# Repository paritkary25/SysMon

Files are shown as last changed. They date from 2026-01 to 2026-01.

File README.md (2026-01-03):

# SysMon
SysMon is a system monitor hardware. It has three parts
- USB hub
- macro keys and a volume knob as an input (knobs are cool)
- three strips of multiple colours showing CPU/GPU/RAM usage
The project is ongoing.

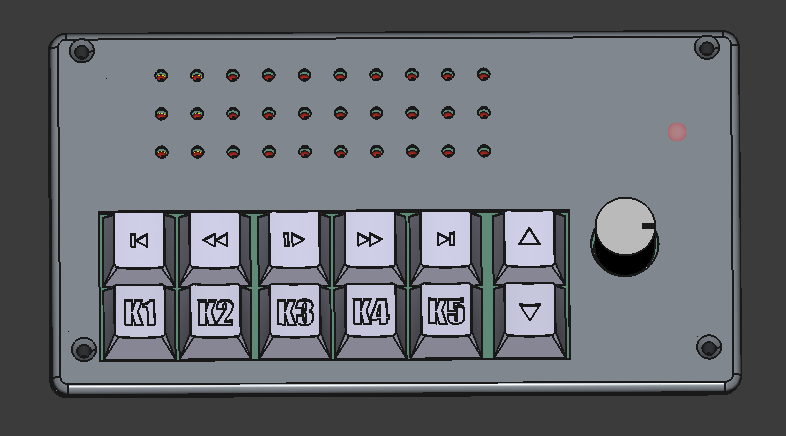
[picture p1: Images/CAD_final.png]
CAD Image


.
├── CAD: Contains all the CADs related to the project
├── PCB: Contains the PCB files
├── Software: Software used in this project
└── USB-C_dim_xtracn: An overkill exercise to obtain the correct placement of the holes of the USB-C module

## Progress
- CAD: Complete and printed
- PCB: Complete and printed
    - The USB hub is working
    - STM32 is yet to be tested
- Software: In progress

## Mechanical CAD

The CAD is 3D printed. The enclosure is made slanted to appear like a table clock. The angle is chosen such that it will look good just below the main monitor. The SysMon uses standard Cherry MX keys. Custom keys can be used.

Some of the STEPs are taken from other open-source projects; a sincere thank you to them.

### Log
The CAD has a minor mistake that I noticed after the printing. The inner side of the back body has the wrong angle. Please correct it before printing for yourself. 

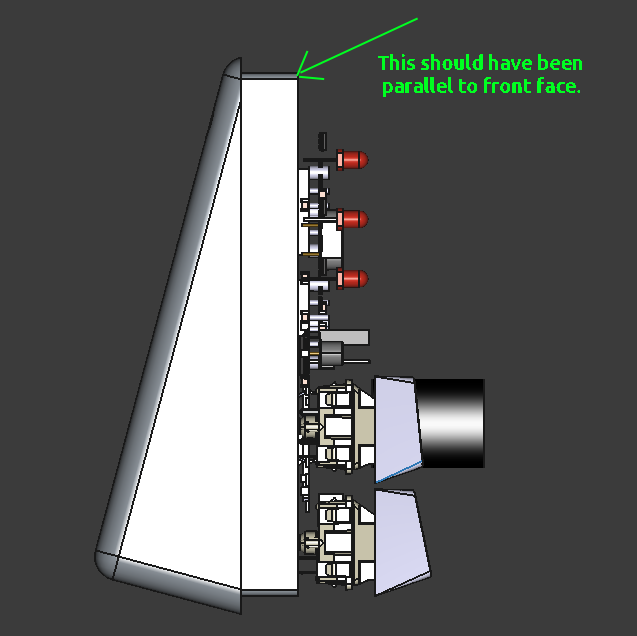
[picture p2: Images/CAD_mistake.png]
CAD Image


## Electronics 
The electronics consist of

- switch matrix
- LED matrix
- volume knob
- Two USB-A upstream ports
- USB-C downstream port for connection to PC
- Adjustable step-down converter module to power the hub
- TI TUSB2036 ASIC-based USB hub 
- STM32L412, very low-powered microcontroller

The PCB is designed on KiCad. For this design, two layers are sufficient. Mixed routing is used with ground planes on both sides. Small series resistors are added in series to the USB-A upstream data bus to prevent ESD issues. Array scanning is used for switches, and row scanning is used for LED lighting.

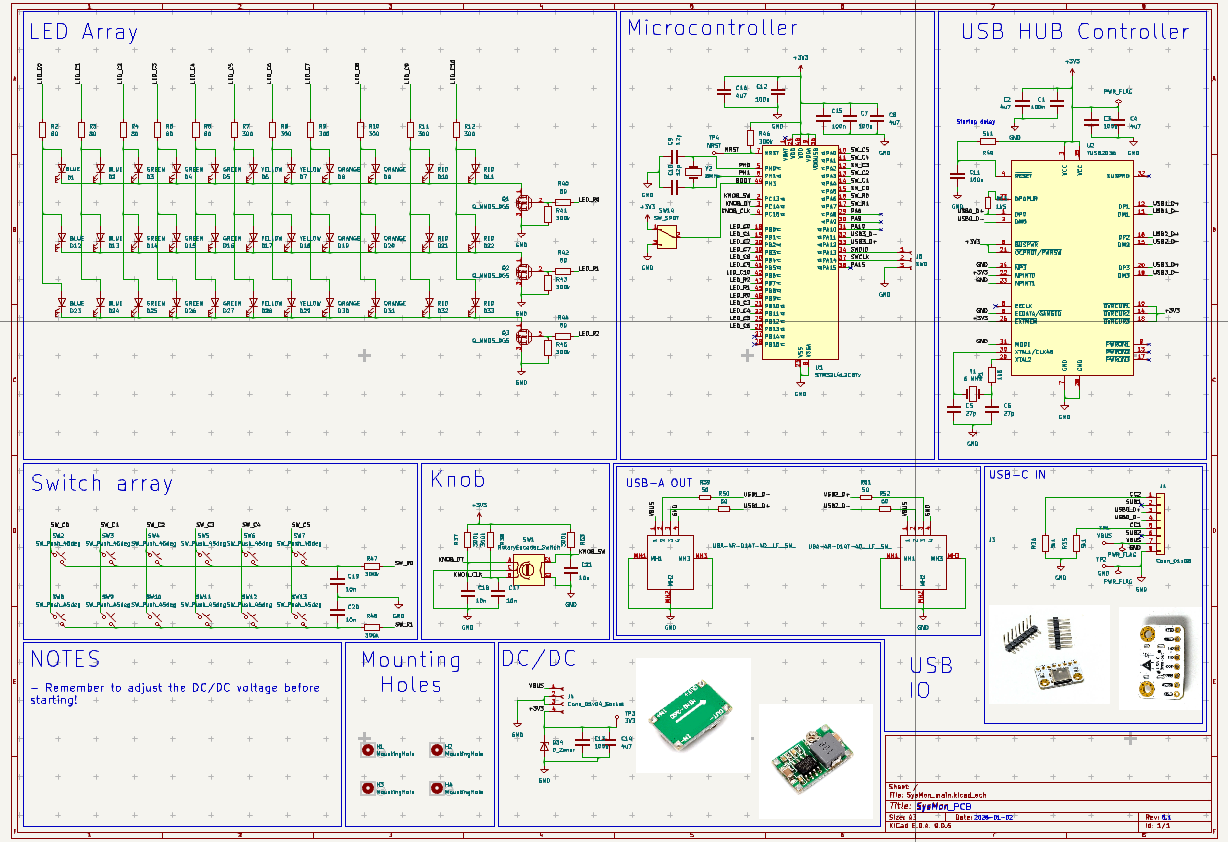
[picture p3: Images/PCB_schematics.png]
Schematics

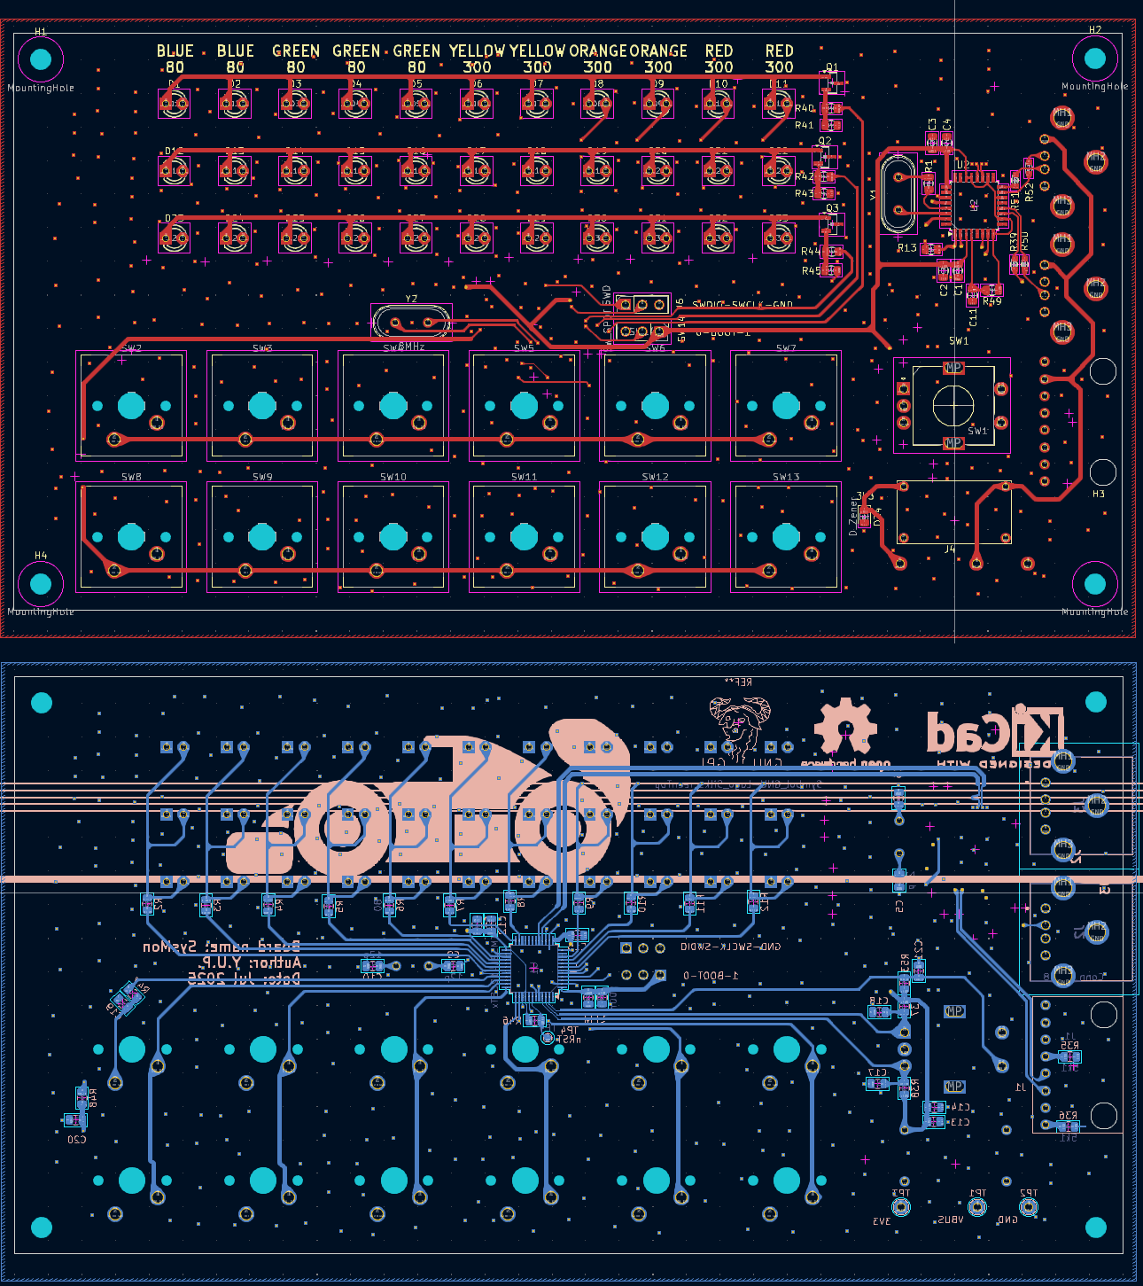
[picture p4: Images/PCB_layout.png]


This hub is not externally powered; take care of what you are plugging in.  The USB-C bus power is set to maximum by pulling CC pins down by 5.1 kOhm (refer to USB-C specifications [USB-C specification](https://www.usb.org/sites/default/files/USB%20Type-C%20Spec%20R2.0%20-%20August%202019_0.pdf) [USB-C PD specifications](https://www.usb.org/sites/default/files/USB-C%20Source%20Power%20Test%20Specification%202021%2005%2024.pdf)))

### Log
- The footprint of the power module is not correct. A workaround involving jumpers and cutting traces is performed.
- The NRST pin of the STM32 is given a test-point only. It is causing discomfort while programming and testing. Please combine it with the SWD programmer pins.

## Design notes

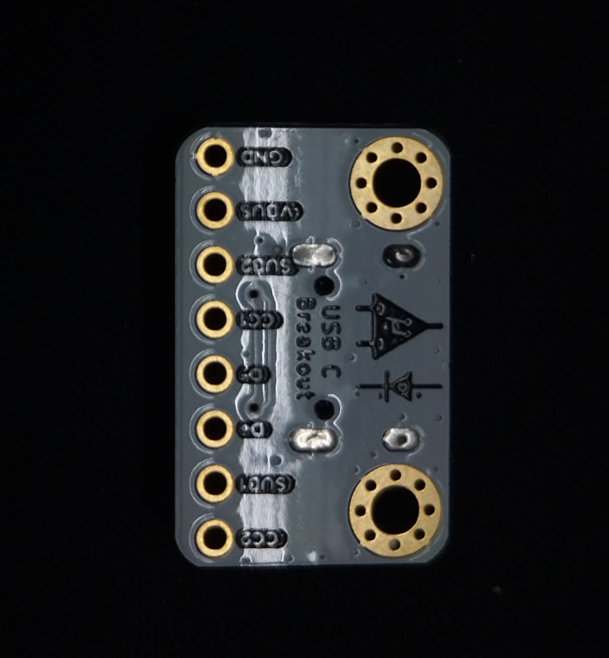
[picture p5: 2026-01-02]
USB-C_dim_xtracn/back.jpg

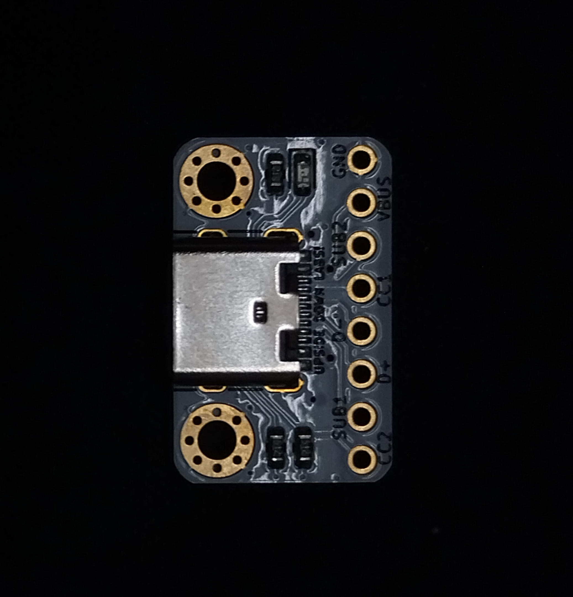
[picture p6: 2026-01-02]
USB-C_dim_xtracn/front.jpg

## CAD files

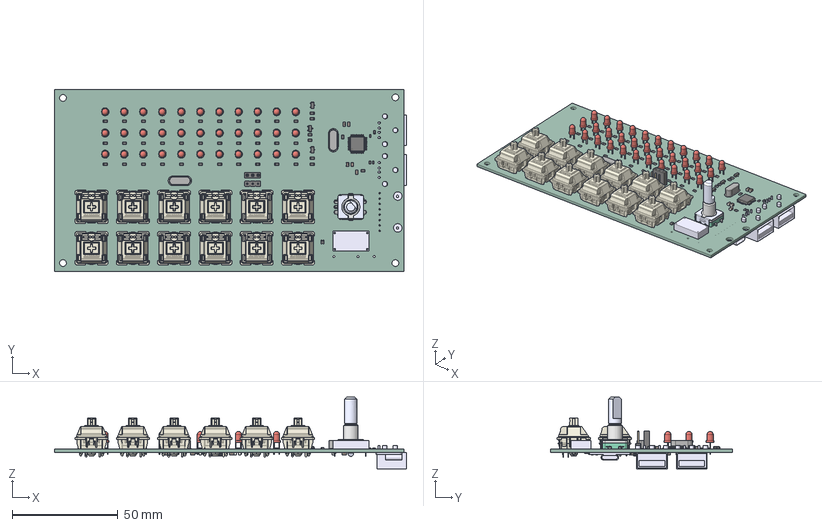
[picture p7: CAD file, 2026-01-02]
PCB/SysMon_main.step
166.2 x 86.0 x 33.9 mm
LED_D3.0mm x 33
R_0805_2012Metric x 48
RD-05C786B9Fyifh x 12
D_0805
PinSocket_1x03_P2.54mm_Vertical
SOT_23 x 3
EC11
Crystal_HC49-4H_Vertical x 2
C_0805_2012Metric x 16
R_0603_1608Metric x 4
PinHeader_1x03_P254mm_Vertical
LQFP_32_7x7mm_P08mm
LQFP_48_7x7mm_P05mm
SysMon_main_PCB

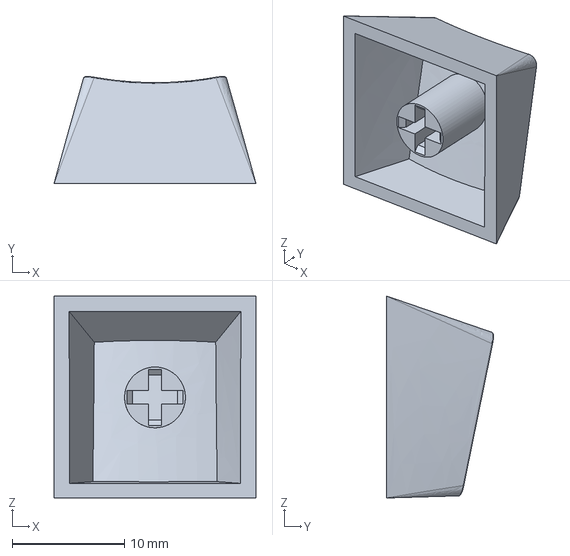
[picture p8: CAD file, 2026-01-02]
CAD/Keys/r2_k4.FCStd
18.0 x 9.53 x 18.0 mm

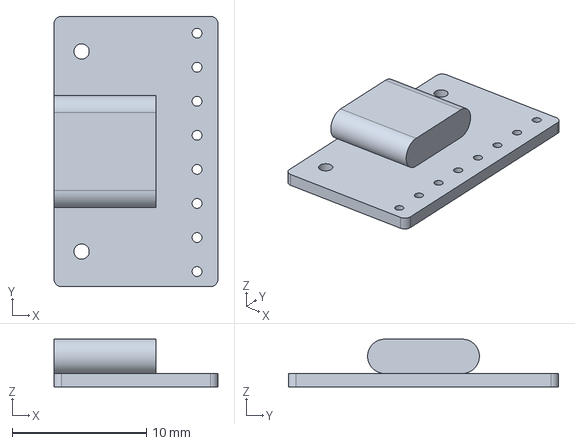
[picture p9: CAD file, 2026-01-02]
USB-C_dim_xtracn/USBC_bo.FCStd
12.2 x 20.2 x 3.56 mm

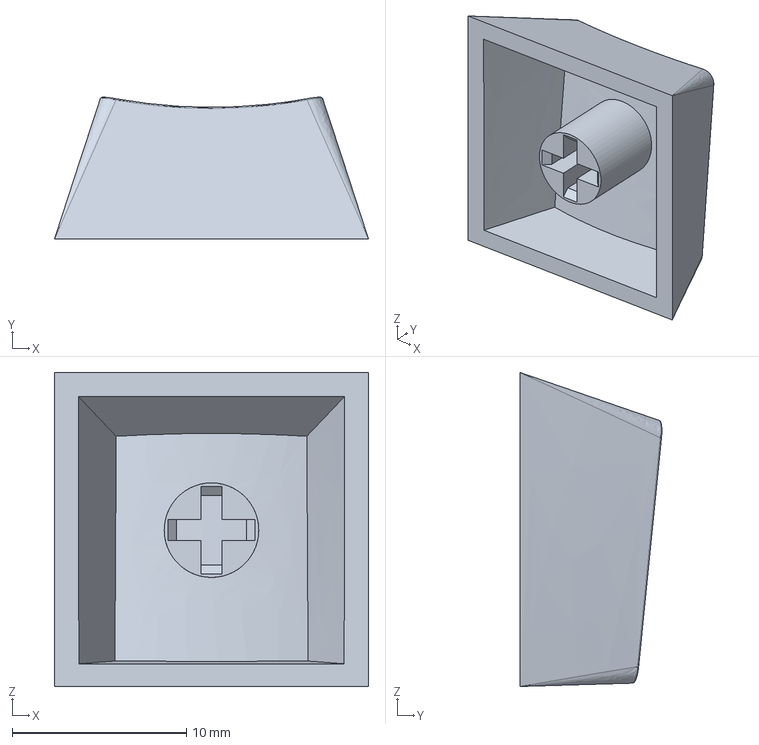
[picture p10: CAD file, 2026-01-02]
CAD/Keys/r1_k1_prev.FCStd
18.0 x 8.13 x 18.0 mm

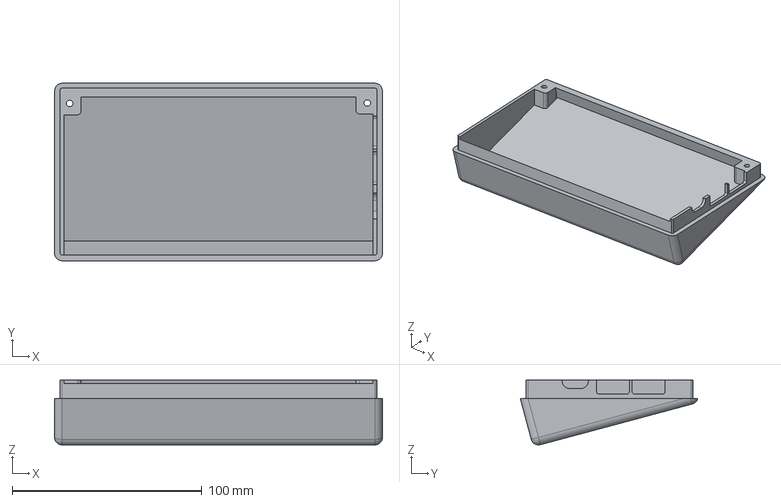
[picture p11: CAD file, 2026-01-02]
CAD/SysMon_CAD-BackCoverBody.step
173.0 x 93.7 x 34.2 mm

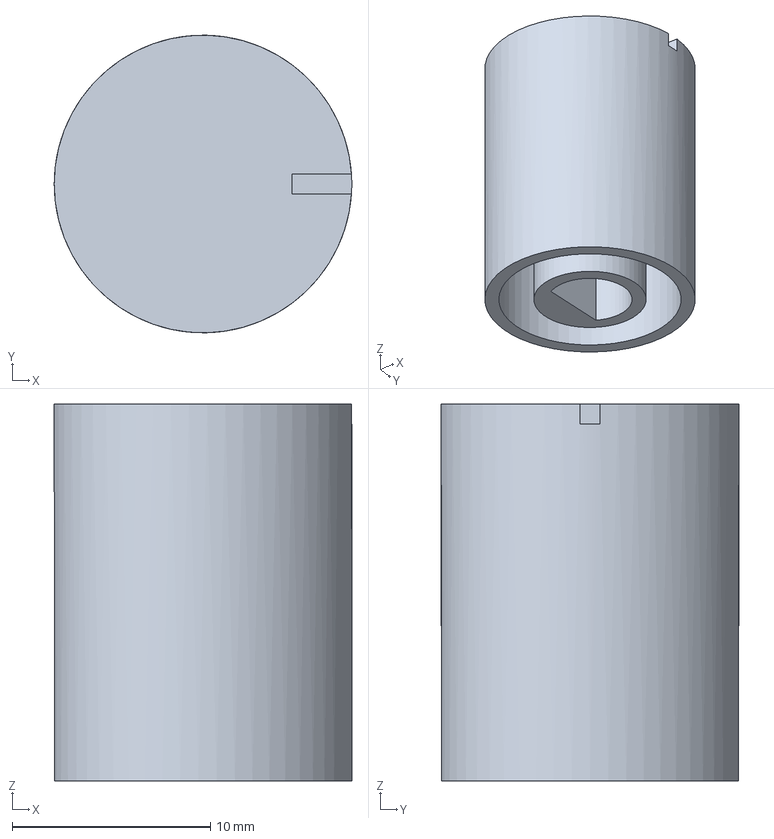
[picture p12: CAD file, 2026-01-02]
CAD/knob.FCStd
15.0 x 15.0 x 19.0 mm

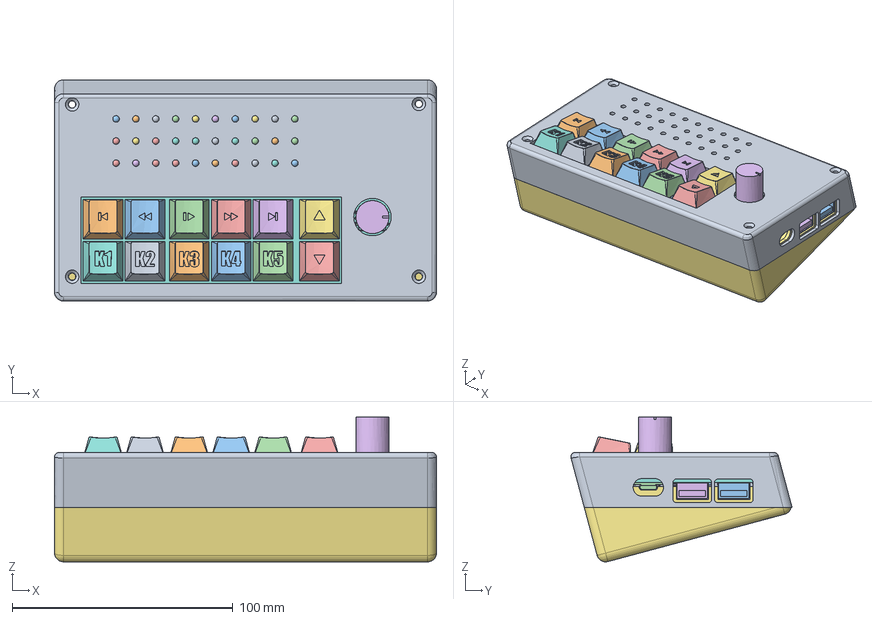
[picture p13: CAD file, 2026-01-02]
CAD/SysMon_CAD.FCStd
173.0 x 100.2 x 65.6 mm
LidBody
r1_k1
r1_k2
r1_k3
r1_k4
r1_k5
r1_k6
r2_k1
r2_k2
r2_k3
r2_k4
r2_k5
r2_k6
KnobBody
BackCoverBody
LED_D3.0mm
LED_D3.0mm002
R_0805_2012Metric096
R_0805_2012Metric098
LED_D3.0mm004
RD-05C786B9Fyifh012
D_0839
R_0805_2012Metric100
R_0805_2012Metric102
R_0805_2012Metric104
PinSocket_1x03_P2.54mm_Vertical002
LED_D3.0mm006
LED_D3.0mm008
R_0805_2012Metric106
R_0805_2012Metric108
R_0805_2012Metric110
R_0805_2012Metric112
RD-05C786B9Fyifh013
RD-05C786B9Fyifh014
SOT_026
EC021
EC022
EC023
EC024
EC025
EC026
EC027
EC028
EC029
R_0805_2012Metric114
LED_D3.0mm010
RD-05C786B9Fyifh015
R_0805_2012Metric116
Crystal_HC49-4H_Vertical004
R_0805_2012Metric118
R_0805_2012Metric120
LED_D3.0mm012
LED_D3.0mm014
R_0805_2012Metric122
LED_D3.0mm016
LED_D3.0mm018
LED_D3.0mm020
R_0805_2012Metric124
LED_D3.0mm022
Crystal_HC49-4H_Vertical006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

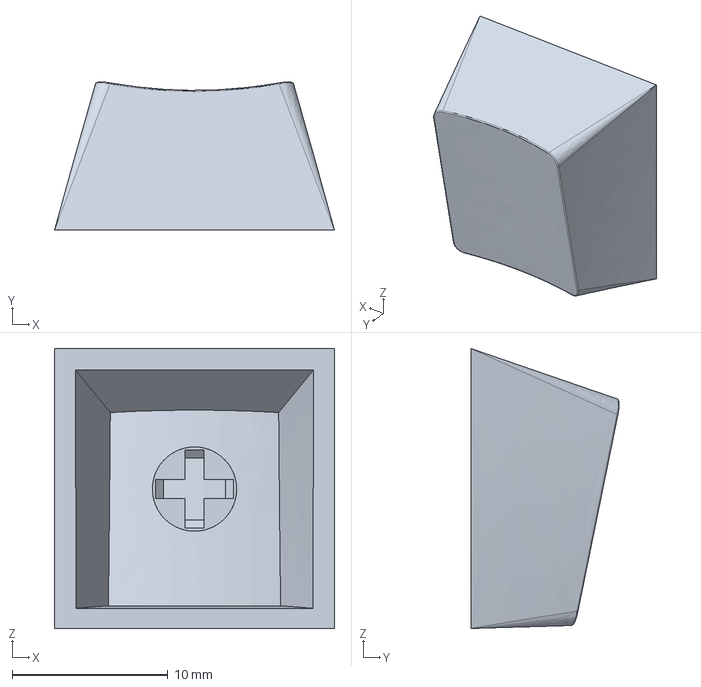
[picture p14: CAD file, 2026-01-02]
CAD/Keys/r2_k0_template.FCStd
18.0 x 9.53 x 18.0 mm

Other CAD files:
CAD/Keys/STEPs/r2_k3-Body.step
CAD/Keys/STEPs/r2_k2-Body.step
USB-C_dim_xtracn/USBC_bo-Body.step
CAD/Keys/r1_k2_seekb.FCStd
CAD/Keys/STEPs/r1_k6_bi-Body.step
CAD/Keys/r1_k5_next.FCStd
CAD/Keys/STEPs/r1_k2_seekb-Body.step
CAD/Keys/r2_k1.FCStd
CAD/Keys/STEPs/r2_k4-Body.step
CAD/EC11.FCStd
CAD/Keys/STEPs/r1_k1_prev-Body.step
CAD/Keys/STEPs/r1_k3_pp-Body.step
CAD/Keys/STEPs/r1_k4_seekf-Body.step
CAD/Keys/STEPs/r1_k5_next-Body.step
CAD/Keys/STEPs/r2_k1-Body.step
CAD/Keys/STEPs/r2_k5-Body.step
CAD/Keys/STEPs/r2_k6_bd-Body.step
CAD/Keys/r1_k0_template.FCStd
CAD/Keys/r1_k3_pp.FCStd
CAD/Keys/r1_k4_seekf.FCStd
CAD/Keys/r1_k6_bi.FCStd
CAD/Keys/r2_k2.FCStd
CAD/Keys/r2_k3.FCStd
CAD/Keys/r2_k5.FCStd
CAD/Keys/r2_k6_bd.FCStd
CAD/SysMon_CAD-BackCoverBody_v1_angle_error.step
CAD/SysMon_CAD-LidBody.step
CAD/SysMon_CAD_old.FCStd
CAD/UBA-4R-D14T-4D.FCStd
CAD/gateron_sw.FCStd

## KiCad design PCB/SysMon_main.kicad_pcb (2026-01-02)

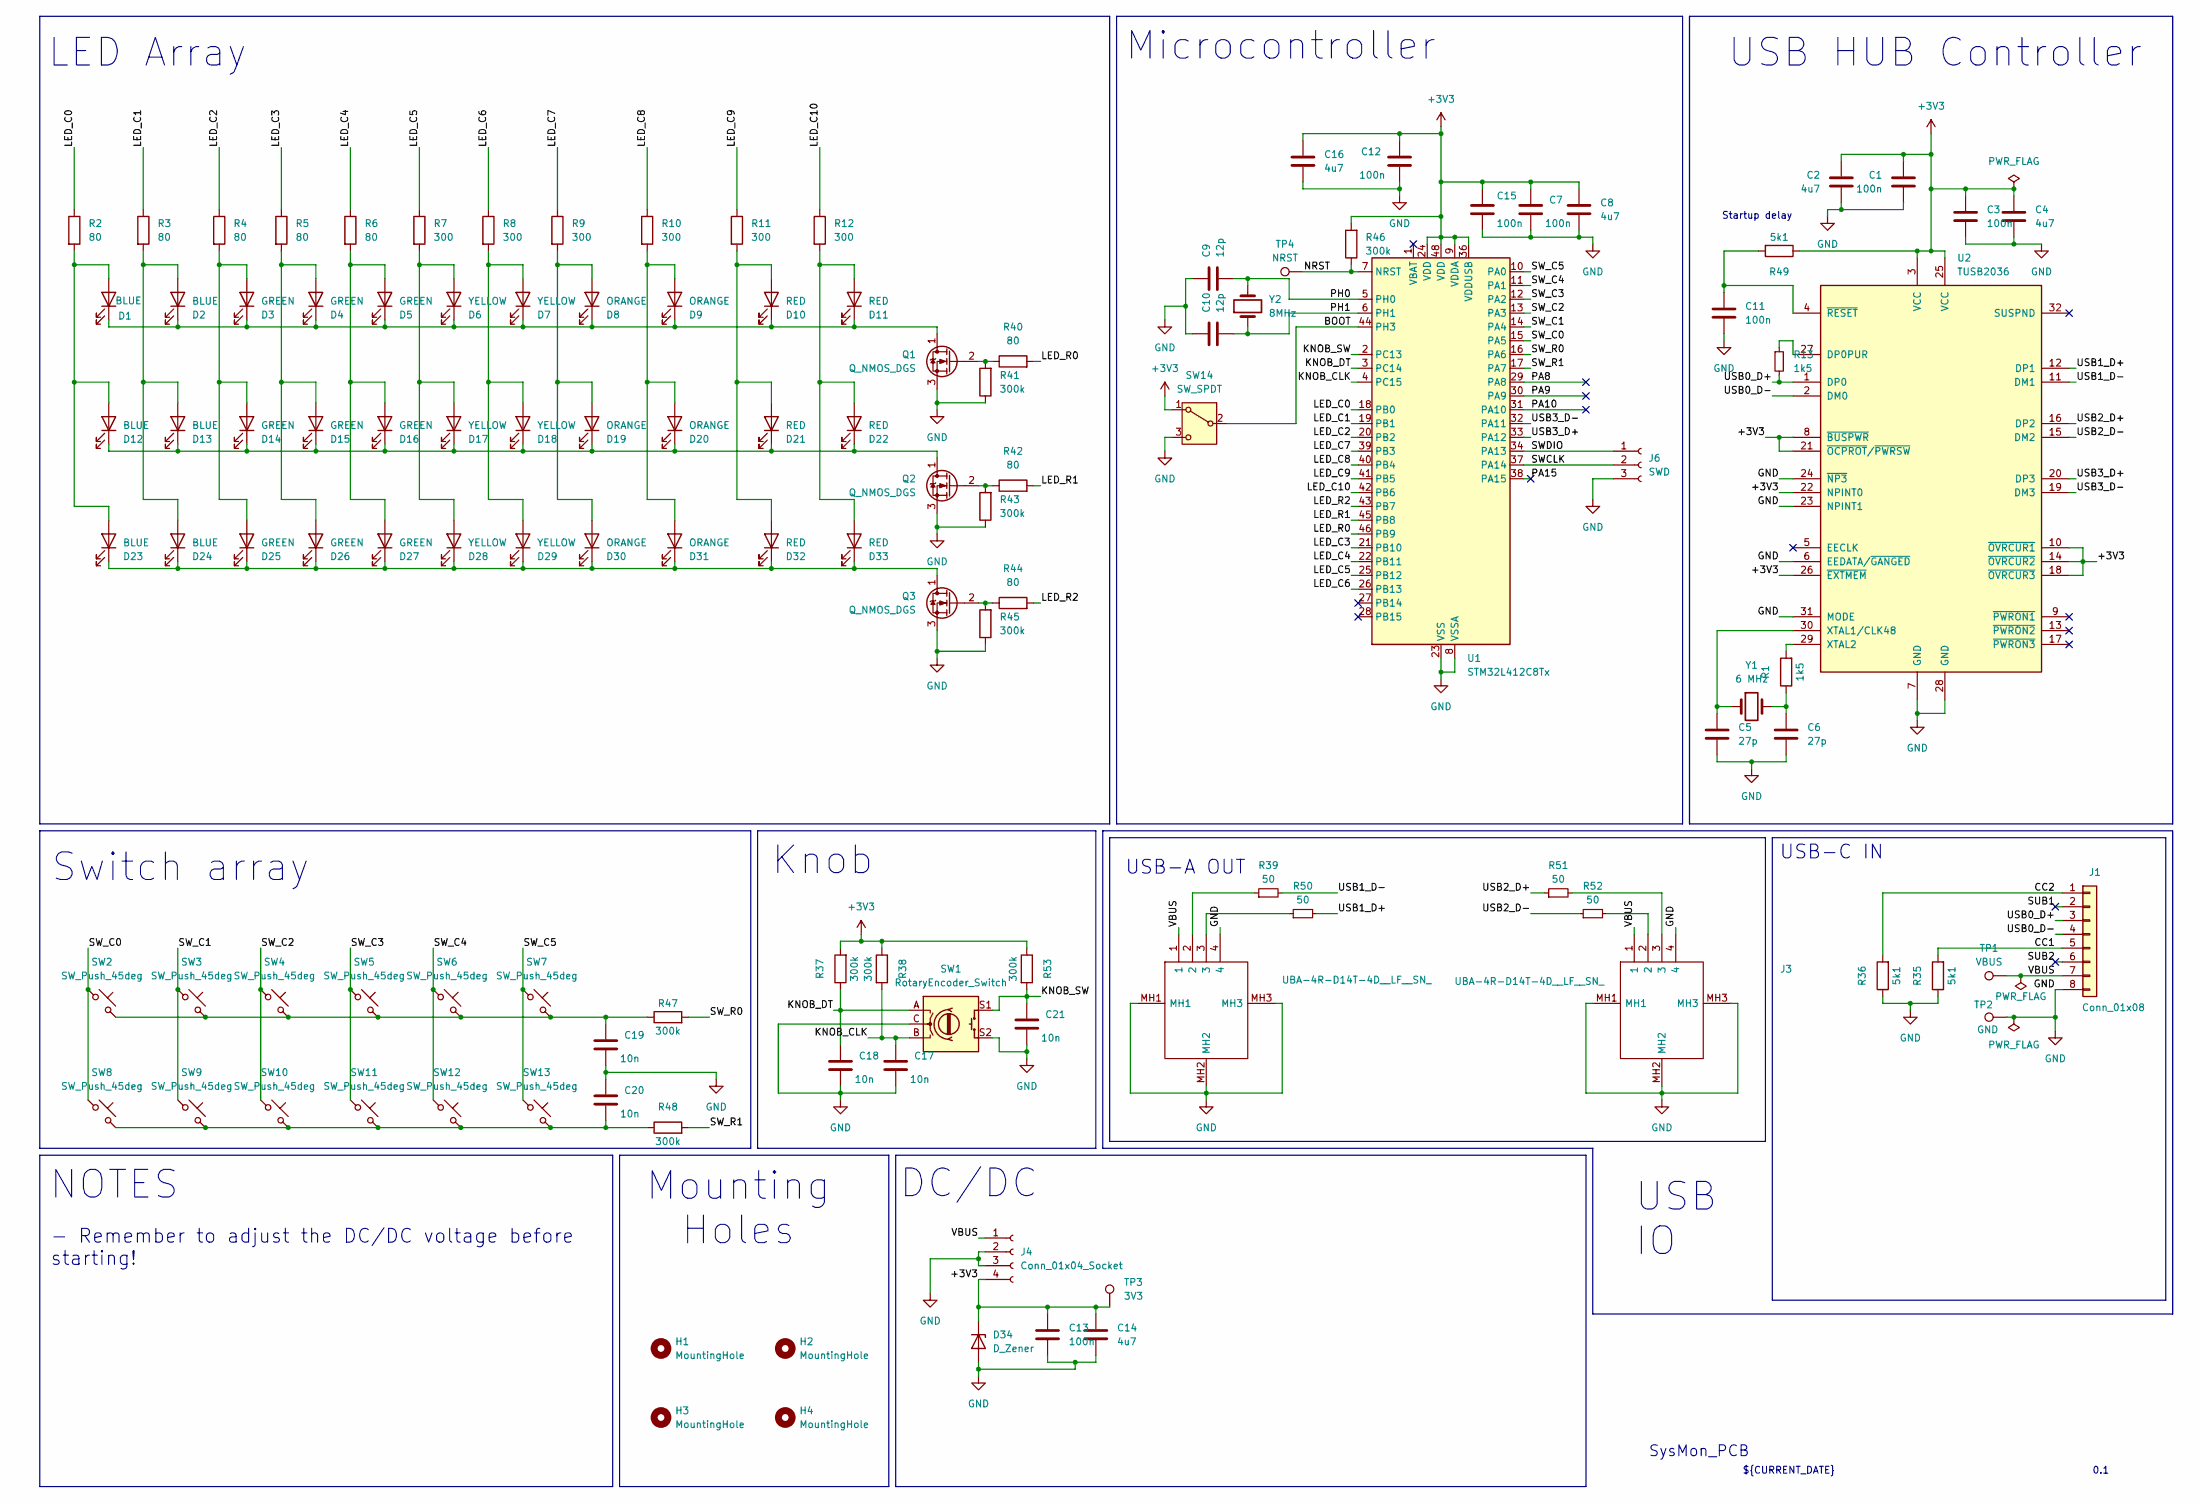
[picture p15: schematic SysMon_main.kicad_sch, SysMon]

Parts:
C1, C3, C7, C11, C12, C13, C15: 100n; C_0805_2012Metric
C2, C4, C8, C14, C16: 4u7; C_0805_2012Metric
C5, C6: 27p; C_0805_2012Metric
C9, C10: 12p; C_0805_2012Metric
C17, C18, C19, C20, C21: 10n; C_0805_2012Metric
D1, D2, D12, D13, D23, D24: BLUE; LED_D3.0mm
D3, D4, D5, D14, D15, D16, D25, D26, D27: GREEN; LED_D3.0mm
D6, D7, D17, D18, D28, D29: YELLOW; LED_D3.0mm
D8, D9, D19, D20, D30, D31: ORANGE; LED_D3.0mm
D10, D11, D21, D22, D32, D33: RED; LED_D3.0mm
D34: D_Zener; D_0805_2012Metric
H1, H2, H3, H4: MountingHole; MountingHole_3.2mm_M3
J1: Conn_01x08; USBC_bo
J2, J3: UBA-4R-D14T-4D__LF__SN_; UBA4RD14T4DLFSN; Manufacturer_Part_Number UBA-4R-D14T-4D (LF)(SN)
J4: Conn_01x04_Socket; Mini_360_DCDC
J6: SWD; PinSocket_1x03_P2.54mm_Vertical
Q1, Q2, Q3: Q_NMOS_DGS; SOT-23
R1, R13: 1k5; R_0805_2012Metric
R2, R3, R4, R5, R6, R40, R42, R44: 80; R_0805_2012Metric
R7, R8, R9, R10, R11, R12: 300; R_0805_2012Metric
R35, R36, R49: 5k1; R_0805_2012Metric
R37, R38, R41, R43, R45, R46, R47, R48, R53: 300k; R_0805_2012Metric
R39, R50, R51, R52: 50; R_0603_1608Metric
SW1: RotaryEncoder_Switch; RotaryEncoder_Alps_EC11E-Switch_Vertical_H20mm
SW2, SW3, SW4, SW5, SW6, SW7, SW8, SW9, SW10, SW11, SW12, SW13: SW_Push_45deg; SW_MX_THT
SW14: SW_SPDT; PinHeader_1x03_P2.54mm_Vertical
TP1: VBUS; TestPoint_THTPad_D2.0mm_Drill1.0mm
TP2: GND; TestPoint_THTPad_D2.0mm_Drill1.0mm
TP3: 3V3; TestPoint_THTPad_D2.0mm_Drill1.0mm
TP4: NRST; TestPoint_Pad_D1.0mm
U1: STM32L412C8Tx; LQFP-48_7x7mm_P0.5mm
U2: TUSB2036; LQFP-32_7x7mm_P0.8mm
Y1: 6 MHz; Crystal_HC49-4H_Vertical
Y2: 8MHz; Crystal_HC49-4H_Vertical

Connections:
+3V3: C1.1, C2.1, C3.1, C4.1, C7.1, C8.1, C12.1, C13.1, C14.1, C15.1, C16.1, D34.1 (K), J4.4, R37.2, R38.1, R46.2, R49.1, R53.1, SW14.1 (A), TP3.1, U1.9 (VDDA), U1.24 (VDD), U1.36 (VDDUSB), U1.48 (VDD), U2.3 (VCC), U2.8 (~BUSPWR), U2.10 (~OVRCUR1), U2.14 (~OVRCUR2), U2.18 (~OVRCUR3), U2.21 (~OCPROT/~PWRSW), U2.22 (NPINT0), U2.25 (VCC), U2.26 (~EXTMEM)
/BOOT: SW14.2 (B), U1.44 (PH3)
/CC1: J1.5, R35.2
/CC2: J1.1, R36.2
/KNOB_CLK: C17.1, R38.2, SW1.B, U1.4 (PC15)
/KNOB_DT: C18.1, R37.1, SW1.A, U1.3 (PC14)
/KNOB_SW: C21.1, R53.2, SW1.S1, U1.2 (PC13)
/LED_C0: R2.1, U1.18 (PB0)
/LED_C1: R3.1, U1.19 (PB1)
/LED_C2: R4.1, U1.20 (PB2)
/LED_C3: R5.1, U1.21 (PB10)
/LED_C4: R6.1, U1.22 (PB11)
/LED_C5: R7.1, U1.25 (PB12)
/LED_C6: R8.1, U1.26 (PB13)
/LED_C7: R9.1, U1.39 (PB3)
/LED_C8: R10.1, U1.40 (PB4)
/LED_C9: R11.1, U1.41 (PB5)
/LED_C10: R12.1, U1.42 (PB6)
/LED_R0: R40.2, U1.46 (PB9)
/LED_R1: R42.2, U1.45 (PB8)
/LED_R2: R44.2, U1.43 (PB7)
/NRST: R46.1, TP4.1, U1.7 (NRST)
/PA8: U1.29 (PA8)
/PA9: U1.30 (PA9)
/PA10: U1.31 (PA10)
/PA15: U1.38 (PA15)
/PH0: C9.2, U1.5 (PH0), Y2.2
/PH1: C10.2, U1.6 (PH1), Y2.1
/SUB1: J1.2
/SUB2: J1.6
/SWCLK: J6.2, U1.37 (PA14)
/SWDIO: J6.1, U1.34 (PA13)
/SW_C0: SW2.1, SW8.1, U1.15 (PA5)
/SW_C1: SW3.1, SW9.1, U1.14 (PA4)
/SW_C2: SW4.1, SW10.1, U1.13 (PA3)
/SW_C3: SW5.1, SW11.1, U1.12 (PA2)
/SW_C4: SW6.1, SW12.1, U1.11 (PA1)
/SW_C5: SW7.1, SW13.1, U1.10 (PA0)
/SW_R0: R47.2, U1.16 (PA6)
/SW_R1: R48.2, U1.17 (PA7)
/USB0_D+: J1.3, R13.2, U2.1 (DP0)
/USB0_D-: J1.4, U2.2 (DM0)
/USB1_D+: R50.2, U2.12 (DP1)
/USB1_D-: R39.2, U2.11 (DM1)
/USB2_D+: R51.1, U2.16 (DP2)
/USB2_D-: R52.1, U2.15 (DM2)
/USB3_D+: U1.33 (PA12), U2.20 (DP3)
/USB3_D-: U1.32 (PA11), U2.19 (DM3)
/VBUS: J1.7, J2.1, J3.1, J4.1, TP1.1
GND: C1.2, C2.2, C3.2, C4.2, C5.2, C6.2, C7.2, C8.2, C9.1, C10.1, C11.2, C12.2, C13.2, C14.2, C15.2, C16.2, C17.2, C18.2, C19.2, C20.1, C21.2, D34.2 (A), J1.8, J2.4, J2.MH1, J2.MH2, J2.MH3, J3.4, J3.MH1, J3.MH2, J3.MH3, J4.2, J4.3, J6.3, Q1.3 (S), Q2.3 (S), Q3.3 (S), R35.1, R36.1, R41.1, R43.1, R45.1, SW1.C, SW1.S2, SW14.3 (C), TP2.1, U1.8 (VSSA), U1.23 (VSS), U1.35 (VSS), U1.47 (VSS), U2.6 (EEDATA/~GANGED), U2.7 (GND), U2.23 (NPINT1), U2.24 (~NP3), U2.28 (GND), U2.31 (MODE)
unnamed: C6.1, R1.1, Y1.2
unnamed: C19.1, R47.1, SW2.2, SW3.2, SW4.2, SW5.2, SW6.2, SW7.2
unnamed: C20.2, R48.1, SW8.2, SW9.2, SW10.2, SW11.2, SW12.2, SW13.2
unnamed: D1.2 (A), D12.2 (A), D23.2 (A), R2.2
unnamed: D1.1 (K), D2.1 (K), D3.1 (K), D4.1 (K), D5.1 (K), D6.1 (K), D7.1 (K), D8.1 (K), D9.1 (K), D10.1 (K), D11.1 (K), Q1.1 (D)
unnamed: D10.2 (A), D21.2 (A), D32.2 (A), R11.2
unnamed: D11.2 (A), D22.2 (A), D33.2 (A), R12.2
unnamed: D12.1 (K), D13.1 (K), D14.1 (K), D15.1 (K), D16.1 (K), D17.1 (K), D18.1 (K), D19.1 (K), D20.1 (K), D21.1 (K), D22.1 (K), Q2.1 (D)
unnamed: D2.2 (A), D13.2 (A), D24.2 (A), R3.2
unnamed: D3.2 (A), D14.2 (A), D25.2 (A), R4.2
unnamed: D4.2 (A), D15.2 (A), D26.2 (A), R5.2
unnamed: D5.2 (A), D16.2 (A), D27.2 (A), R6.2
unnamed: D6.2 (A), D17.2 (A), D28.2 (A), R7.2
unnamed: D7.2 (A), D18.2 (A), D29.2 (A), R8.2
unnamed: D8.2 (A), D19.2 (A), D30.2 (A), R9.2
unnamed: D9.2 (A), D20.2 (A), D31.2 (A), R10.2
unnamed: D23.1 (K), D24.1 (K), D25.1 (K), D26.1 (K), D27.1 (K), D28.1 (K), D29.1 (K), D30.1 (K), D31.1 (K), D32.1 (K), D33.1 (K), Q3.1 (D)
unnamed: J2.2, R39.1
unnamed: J2.3, R50.1
unnamed: J3.2, R52.2
unnamed: J3.3, R51.2
unnamed: Q1.2 (G), R40.1, R41.2
unnamed: Q2.2 (G), R42.1, R43.2
unnamed: Q3.2 (G), R44.1, R45.2
unnamed: R13.1, U2.27 (DP0PUR)
unnamed: C5.1, U2.30 (XTAL1/CLK48), Y1.1
unnamed: R1.2, U2.29 (XTAL2)
unnamed: C11.1, R49.2, U2.4 (~RESET)

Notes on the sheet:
0.1
DC/DC
Mounting Holes
USB-A OUT
NOTES
Startup delay
${CURRENT_DATE}
USB-C IN
LED Array
USB IO
Switch array
USB HUB Controller
Knob
Microcontroller
SysMon_PCB
- Remember to adjust the DC/DC voltage before starting!

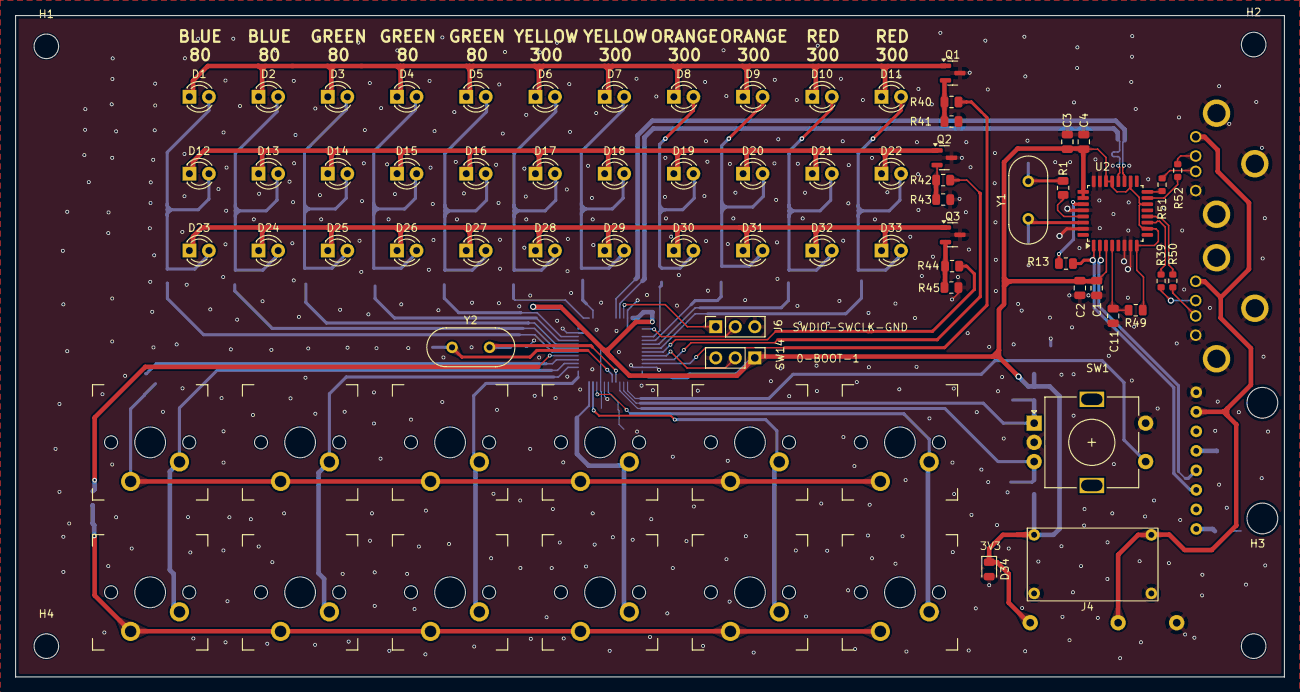
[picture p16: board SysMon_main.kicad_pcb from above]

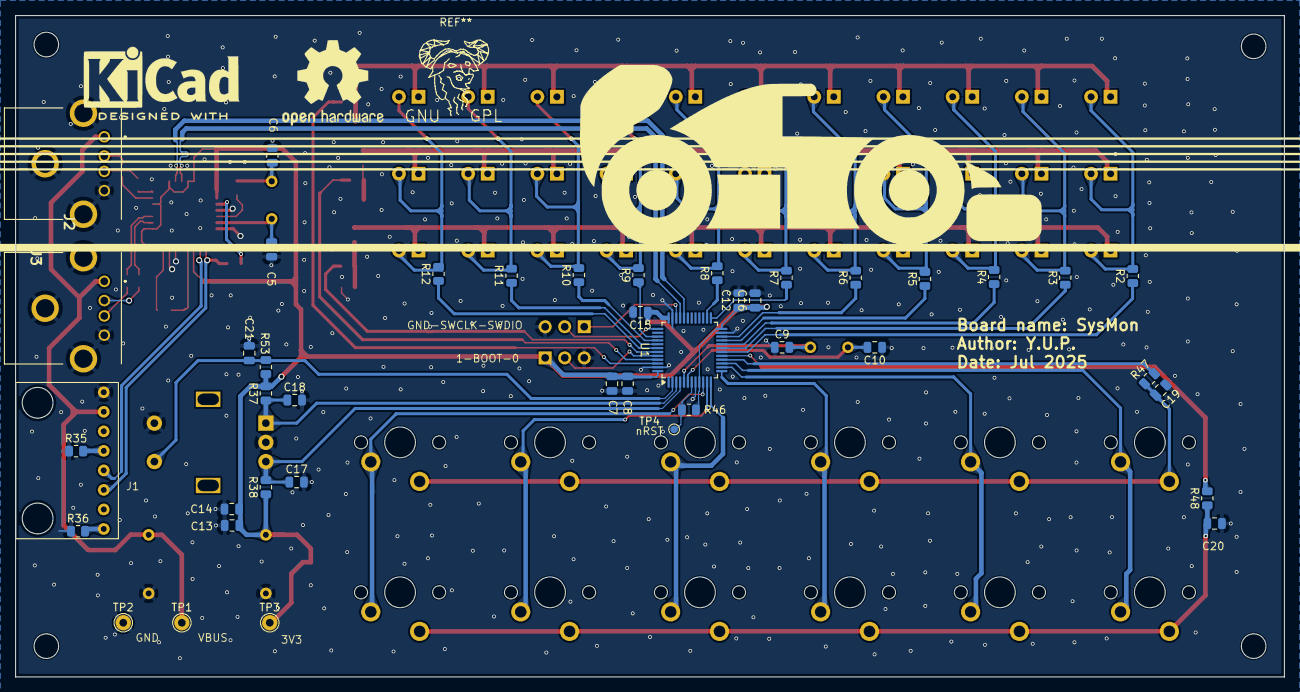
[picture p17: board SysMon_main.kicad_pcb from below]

Board: 2 copper layers, 165.0 x 86.0 mm, 121 parts (43 on the bottom side), 72 nets.

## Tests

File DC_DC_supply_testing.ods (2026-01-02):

Vout (V) | Iout (A) | V_error | Power (W)
3.34 | 0 | 0.04 | 0
3.34 | 0.02 | 0.04 | 0.0668
3.34 | 0.04 | 0.04 | 0.1336
3.34 | 0.09 | 0.04 | 0.3006
3.34 | 0.11 | 0.04 | 0.3674
3.34 | 0.14 | 0.04 | 0.4676
3.34 | 0.25 | 0.04 | 0.835
3.34 | 0.29 | 0.04 | 0.9686
3.34 | 0.56 | 0.04 | 1.8704

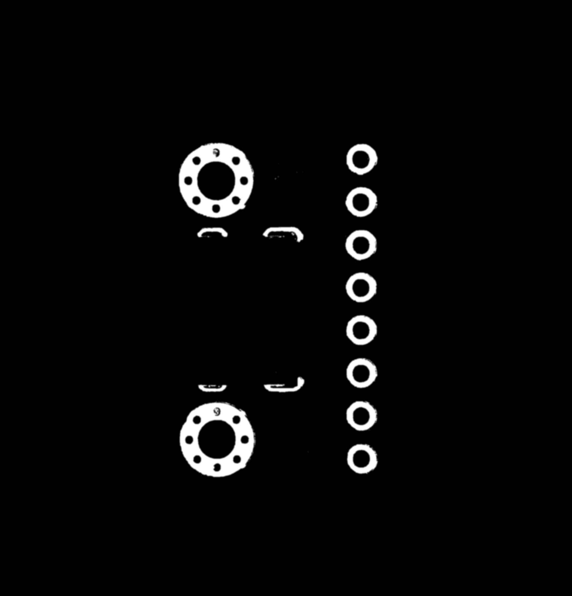
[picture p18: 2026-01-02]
USB-C_dim_xtracn/test.jpg

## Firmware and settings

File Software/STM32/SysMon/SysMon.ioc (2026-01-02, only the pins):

Mcu.UserName=STM32L412CBTx
PA0.Signal=GPIO_Output
PA1.Signal=GPIO_Output
PA11.Signal=USB_DM
PA12.Signal=USB_DP
PA2.Signal=GPIO_Input
PA3.Signal=GPIO_Analog
PA4.Signal=GPIO_Output
PA5.Signal=GPIO_Output
PA6.Signal=GPIO_Input
PA7.Signal=GPIO_Input
PB0.Signal=GPIO_Output
PB1.Signal=GPIO_Output
PB10.Signal=GPIO_Output
PB11.Signal=GPIO_Output
PB12.Signal=GPIO_Output
PB13.Signal=GPIO_Output
PB2.Signal=GPIO_Output
PB5.Signal=GPIO_Output
PB6.Signal=GPIO_Output
PB7.Signal=GPIO_Output
PB8.Signal=GPIO_Output
PB9.Signal=GPIO_Output
PC13.Signal=GPIO_Input
